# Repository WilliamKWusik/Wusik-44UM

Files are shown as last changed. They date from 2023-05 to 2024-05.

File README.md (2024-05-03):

# Wusik 44UM
 4x4 USB MIDI Controller With RGB LEDs

USB MIDI Controller Using the Arduino Pro Micro (small Leonardo) ATMega32u4
Fully Programable with Windows, MAC and Linux direct support (no drivers needed). Just plug into the computer and use. By default it sends notes for each button.

Featuring:

- 32 x RGB LEDs (2 per button, on the left and right sides);
- 18 x Buttons (no matrix, so any combination of buttons can be detected);
- 3D Printed Case and Buttons. Unit size: 15 x 15 x 20 cm (rubber feet excluded);
- Windows, MAC and Linux USB MIDI HID Device Compatible (no drivers needed);
- Windows and MAC App for customizing buttons and leds. Using this app you can configure everything and save into the unit's EEPROM memory;
- Multiple options for setting the device directly: MIDICC, Note On/Off, Note On/Off Latch. Just press and hold both top buttons for a few seconds to enter the configuration swap option;
- The unit also receives MIDI which can be used to set the RGB LEDs using note on/off. This is great for when you want to change LEDs with a sequencer or create your own App to handle LEDs. One particular note will turn on and off the unit hanlding of LEDs and will only react to input notes to set leds.

Support this project by using any of the links below.

https://www.patreon.com/williamkwusik

https://ko-fi.com/williamkalfelz

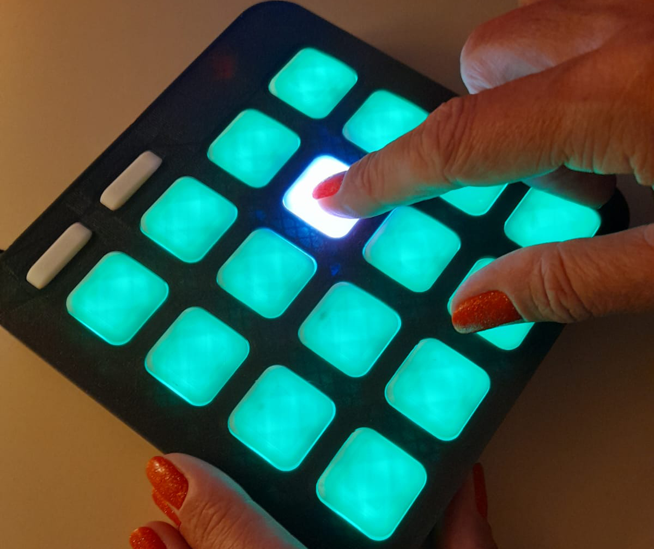
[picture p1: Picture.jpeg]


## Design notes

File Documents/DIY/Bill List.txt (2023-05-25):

You will need to source the following items (not included in this kit) and solder everything. No PCB is required as we will solder everything directly to the Arduino Pro Micro board.

-    Arduino Pro Micro (based on the ATmega32U4). This is the small board, NOT the Leonardo one (see pictures above). Don't get one with headers soldered and don't solder the headers if they come with.;
-    USB Cable to connect the Arduino Pro Micro to the computer. Be sure it's a DATA cable as there are some cheap charger cables around the internet;
-    32 RGB LEDs in a 5050 5 Volts (5V) LED Strip that uses the Ws2812b chip format and the size you can see in the pictures above. But the size should be 12mm between each LED and 16.6 between each cutting point. 60 LEDs per Meter. The strip must NOT be covered with any protection, and should be raw;
-    6x6x5mm Button Switches (see pictures above);
-    Soldering Iron and Solder (get one that has a flux core);
-    Wires to connect buttons to the Arduino board. See the pictures above for an example. I use those rainbow cables and just detach the wires as I need. 
-    Super Glue to hold things together inside the case.

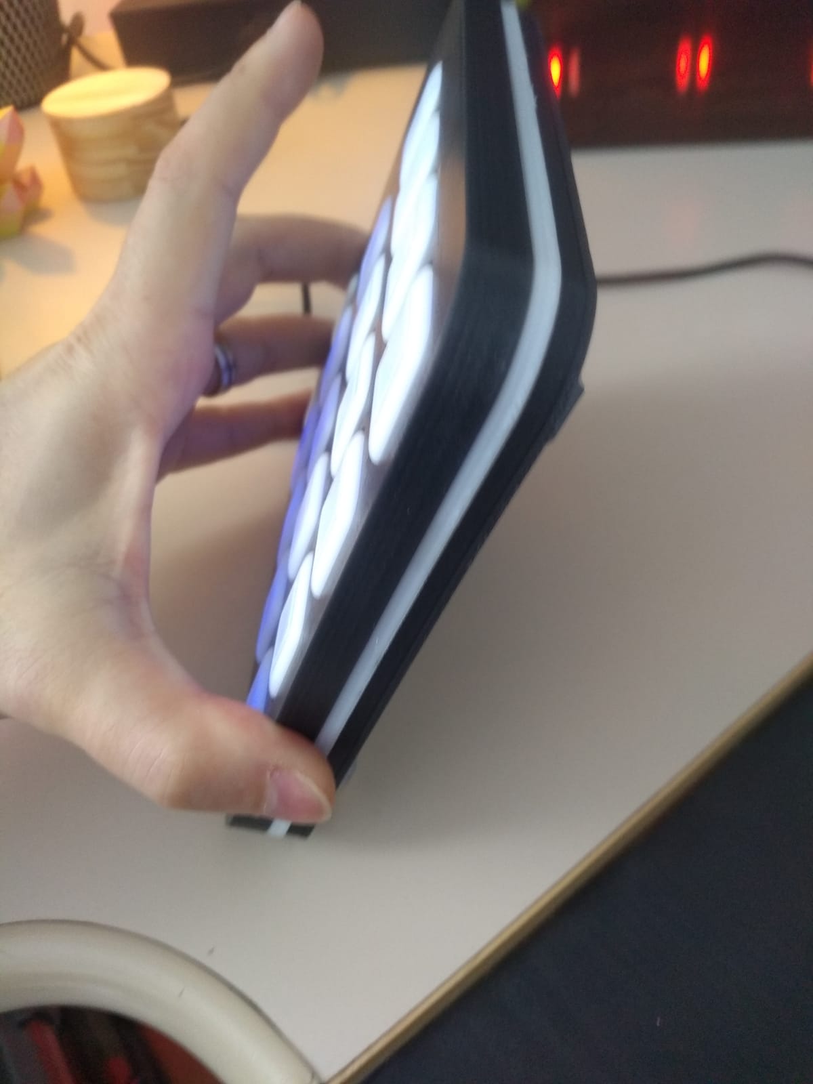
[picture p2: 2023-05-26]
Images/Pictures (3).jpeg

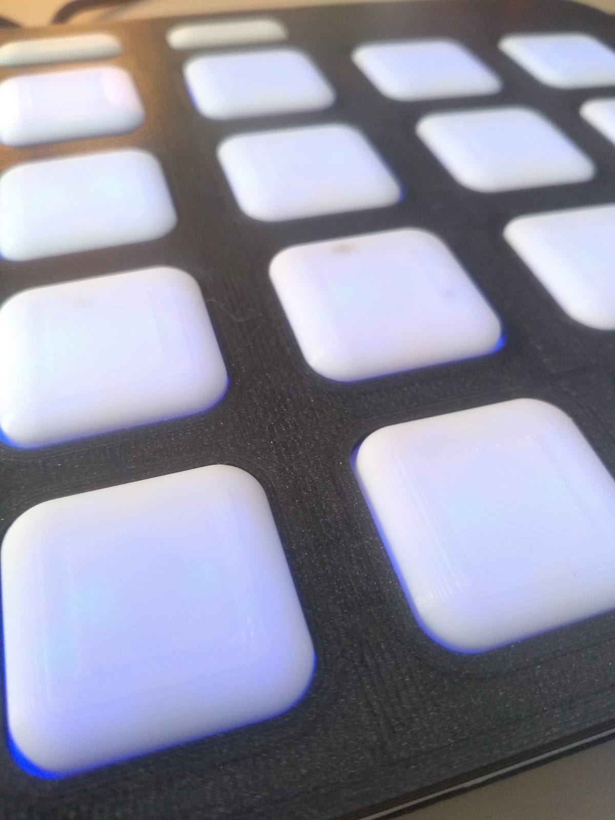
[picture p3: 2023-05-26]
Images/Pictures (2).jpeg

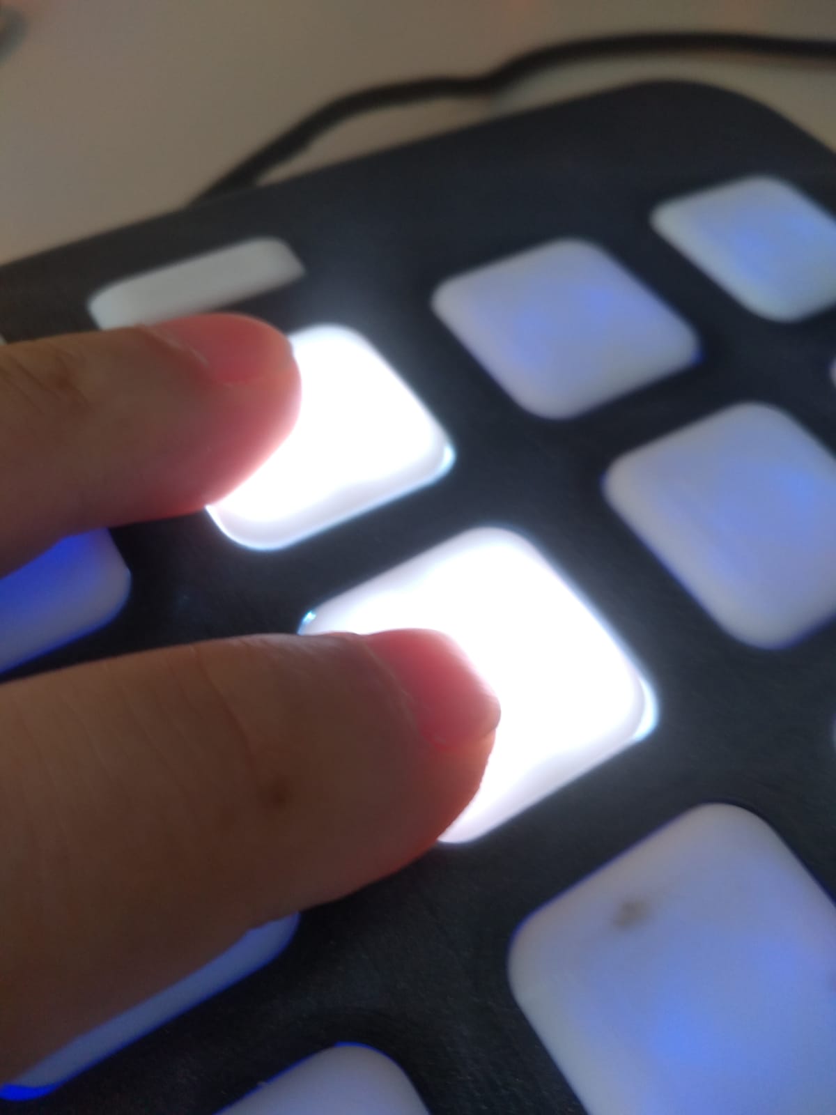
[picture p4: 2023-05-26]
Images/Pictures (4).jpeg

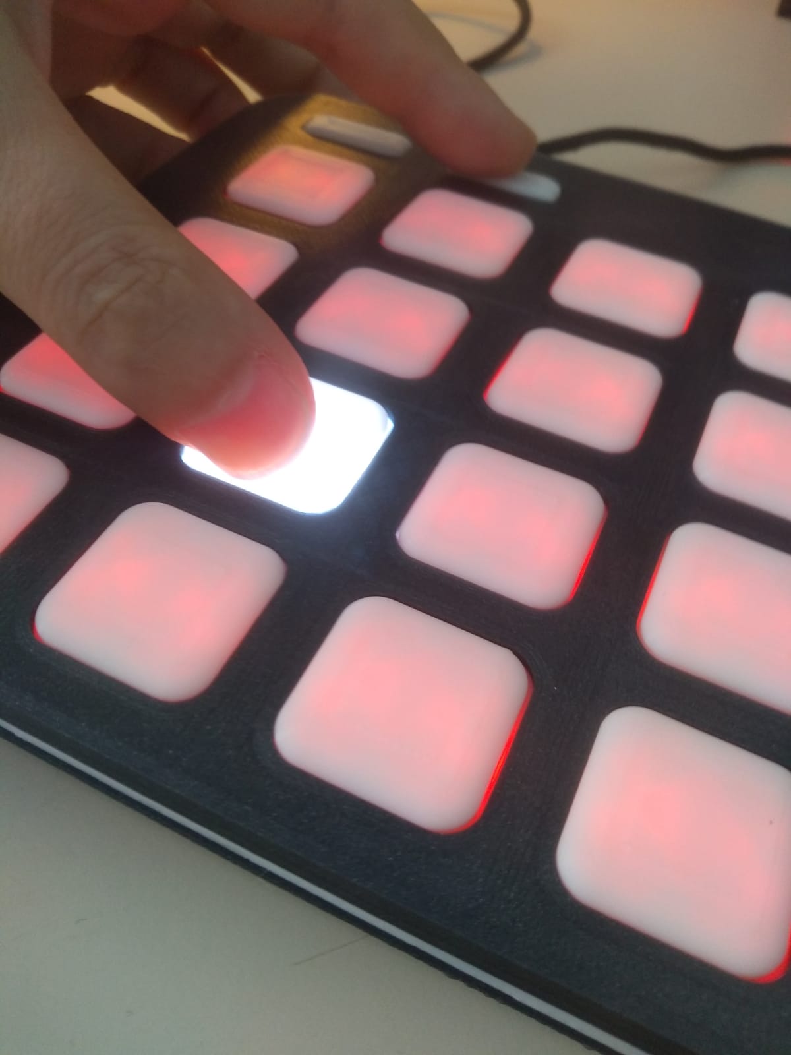
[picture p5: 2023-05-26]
Images/Picture (1).jpeg

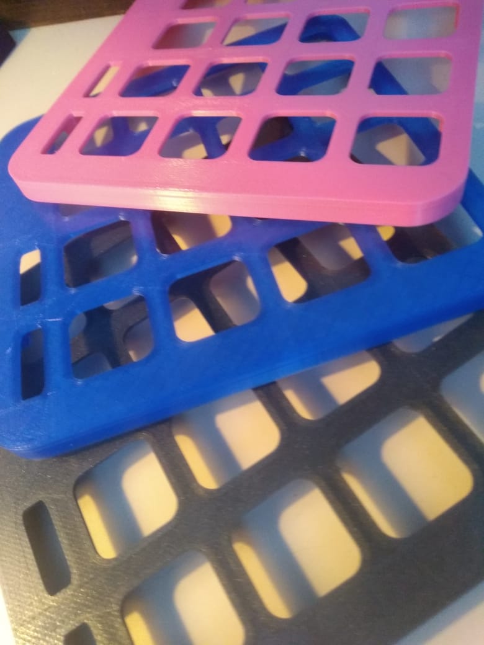
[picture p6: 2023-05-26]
Images/Picture (4).jpeg

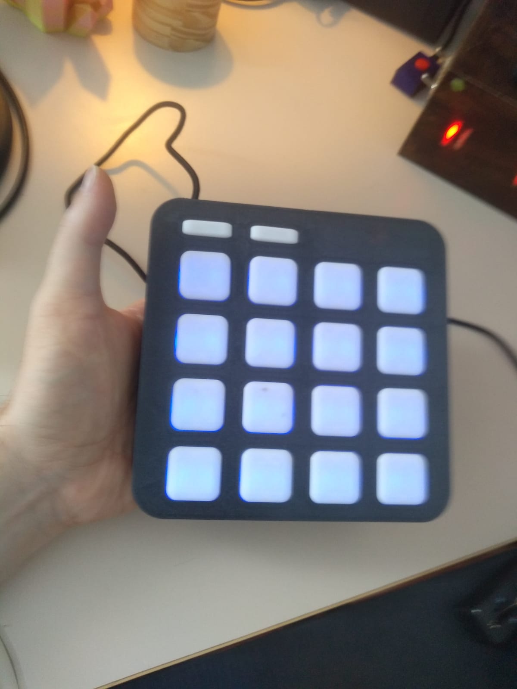
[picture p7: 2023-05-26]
Images/Pictures (1).jpeg

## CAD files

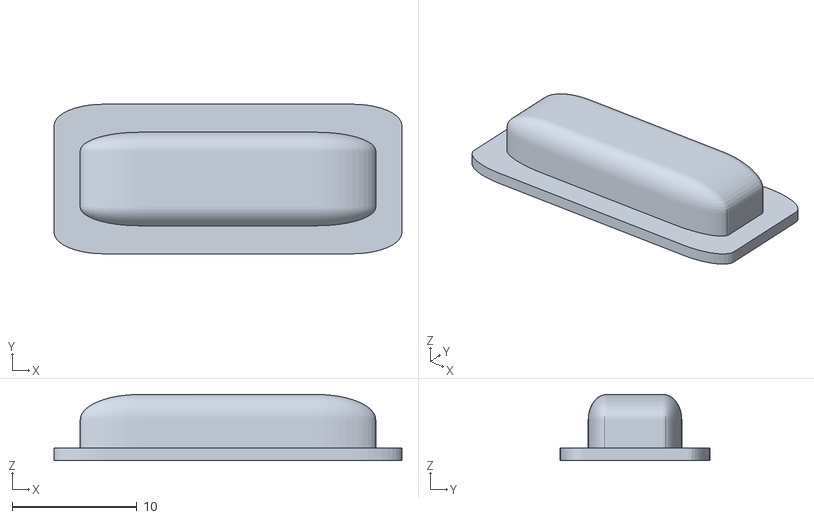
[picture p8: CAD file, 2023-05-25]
Wusik_44UM_STL/Button Medium.stl
27.9 x 12.0 x 5.30

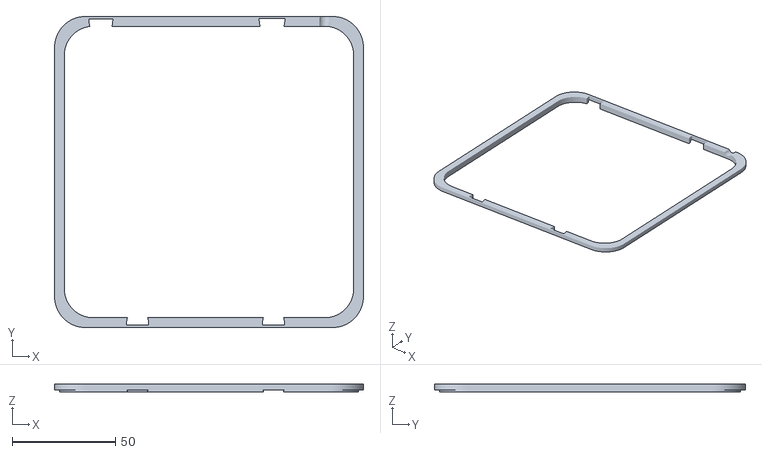
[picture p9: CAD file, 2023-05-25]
Wusik_44UM_STL/White Border.stl
150.0 x 151.0 x 3.91

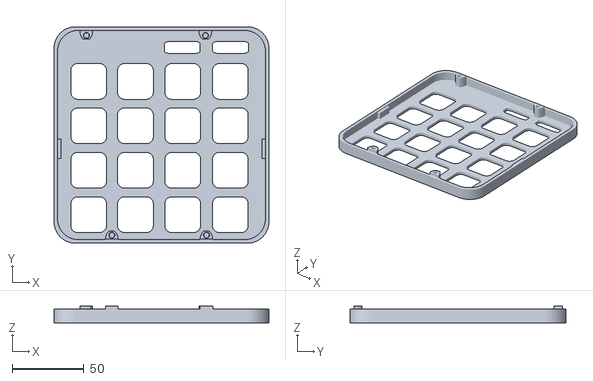
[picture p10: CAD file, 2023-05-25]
Wusik_44UM_STL/Top.stl
150.0 x 151.0 x 11.6

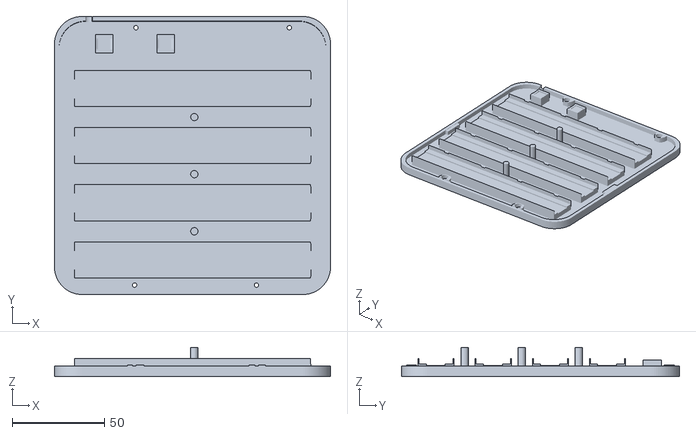
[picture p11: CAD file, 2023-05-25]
Wusik_44UM_STL/Bottom.stl
150.0 x 151.0 x 15.9

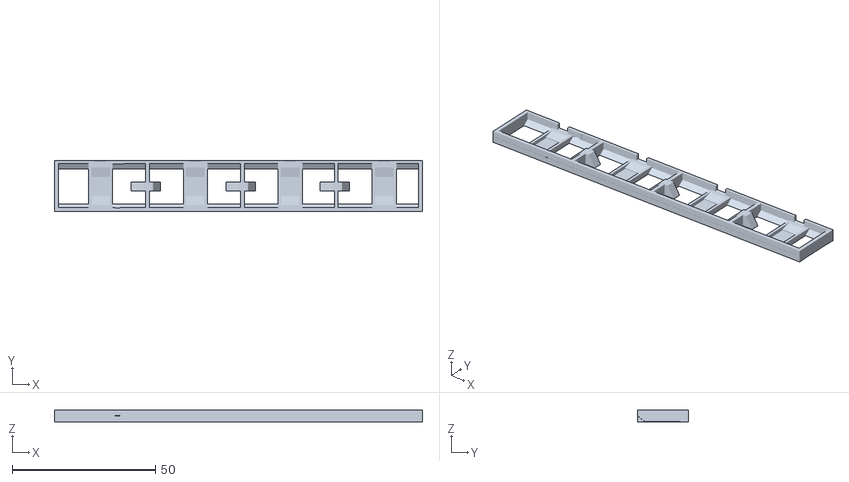
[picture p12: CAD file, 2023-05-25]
Wusik_44UM_STL/Inside Covers.stl
128.4 x 17.9 x 4.14

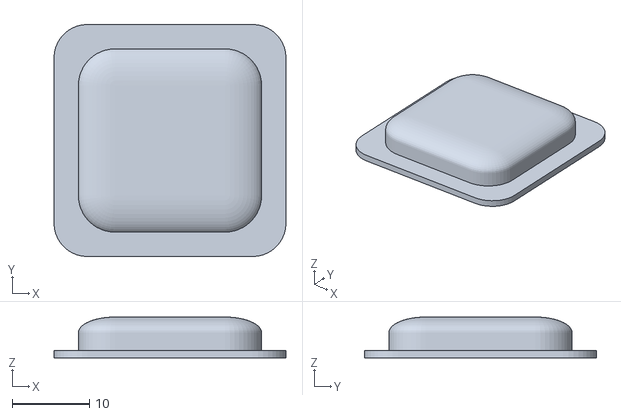
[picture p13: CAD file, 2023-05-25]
Wusik_44UM_STL/Button Large.stl
30.0 x 30.0 x 5.30

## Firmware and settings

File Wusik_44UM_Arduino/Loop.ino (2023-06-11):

/*
   Created by William Kalfelz @ Wusik.com (c) 2023
*/
//
// ------------------------------------------------------------------------------------------------------------------------------------
inline void checkButton(byte pin)
{
  if (digitalRead(pin) == LOW)
  {
    if (buttonsCounter[buttonsList[pin]] < 250) buttonsCounter[buttonsList[pin]]++;
    if (buttonsCounter[buttonsList[pin]] == BUTTON_DEBOUCE_COUNTER) setVarBit(buttonsDown, buttonsList[pin], true);
    if (buttonsCounter[buttonsList[pin]] >= BUTTON_DEBOUCE_COUNTER) setVarBit(buttonsHolding, buttonsList[pin], true);
  }
  else if (buttonsCounter[buttonsList[pin]] >= BUTTON_DEBOUCE_COUNTER)
  {
    buttonsCounter[buttonsList[pin]] = 0;
    setVarBit(buttonsReleased, buttonsList[pin], true);
    setVarBit(buttonsHolding, buttonsList[pin], false);
  }
}
//
// ------------------------------------------------------------------------------------------------------------------------------------
void loop()
{
  checkButton(0);
  checkButton(1);
  checkButton(2);
  checkButton(3);
  checkButton(4);
  checkButton(5);
  checkButton(6);
  checkButton(7);
  checkButton(8);
  checkButton(9);
  checkButton(10);
  checkButton(14);
  checkButton(15);
  checkButton(16);
  checkButton(18);
  checkButton(19);
  checkButton(20);
  checkButton(21);
  //
  if (currentMode == 0) normalMode();
  #if HOLD_TOP_BUTTONS_SWAP_CONFIGURATION
    else if (currentMode == 1) swapConfigurationMode();
  #endif
  //
  if (flushMIDI) 
  { 
    MidiUSB.flush(); 
    flushMIDI = false; 
  }
  //  
  midiRX = MidiUSB.read();
  if (midiRX.header != 0) midiReceive();
  //
  buttonsDown = buttonsReleased = 0;
  //
  if (updateFromFlash != 0)
  {
    updateFromFlash--;
    if (updateFromFlash == 0) updateButtonsOffColor();
  }
  //
  RGBBlink();
}

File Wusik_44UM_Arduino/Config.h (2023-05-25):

/*
 * Created by William Kalfelz @ Wusik.com (c) 2023
 */
//
// ------------------------------------------------------------------------------------------------------------------------------------
#define FACTORY_RESET 0 // When you set this, upon startup the unit will ask the buttons to be pressed in this order: small-top-left, small-top-right, large-top-right to large-top-left, continue on the next line left and so on //
//
#define CURRENT_DATA_VERSION 1
#define RGBLEDS_PIN 30
#define RGBLEDS_COUNT 32
#define INTRO_ANIMATION 1
#define INTRO_ANIMATION_SPEED 40
#define INTRO_ANIMATION_SPEED_HOLD 200
#define MAX_BUTTON_PIN 21
#define MAX_PAGES 7
#define MAX_CUSTOM_COLORS 16
#define HOLD_TOP_BUTTONS_SWAP_CONFIGURATION 1
#define BUTTON_DEBOUCE_COUNTER 60
#define RGB_BLINK_SLOW 1220
#define RGB_BLINK_FAST 720
#define MAX_SYSEX_BUFFER 24
//
// ------------------------------------------------------------------------------------------------------------------------------------
enum
{
  kOff = 0, kWhite, kRed, kGreen, kBlue, kRed_Soft, kGreen_Soft, kBlue_Soft, kCustom1,
  kNothing = 0, kNoteOnOff, kNoteOnOffLatch, kMIDI_CC, kActionOnRelease, kMIDI_CC_Flip, kActionOnHold, kAudioLoop,
  kNextPage = 0, kPreviousPage, kPanic, kGoToPage
};

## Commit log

2023-05-25 DIY Docs Added
    [Bottom.stl, Button Large.stl, Button Medium.stl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]
2023-06-12 Samples added
